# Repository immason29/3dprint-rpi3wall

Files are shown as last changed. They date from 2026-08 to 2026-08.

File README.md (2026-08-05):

# Raspberry Pi 3 wall-mount vented case

A one-piece, support-free case for a **Raspberry Pi 3 Model B** that screws flat to a
plywood wall and holds the board **20 mm off the wall** so air can move underneath it.

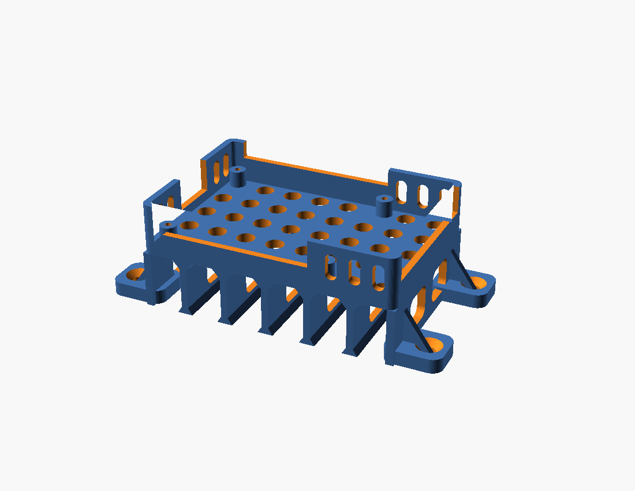
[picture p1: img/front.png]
front


## How it breathes

The case is two stacked structures. The lower one is a set of seven fins that run across
the *short* axis of the board; they carry the whole case on four countersunk ears that sit
flat against the plywood. Mounted with the long edge horizontal, those fins become vertical
chimneys — cool air enters along the bottom edge, rises through the 36 vent holes in the
back plate, passes over the board, and leaves through the open top and the wide-open port
edges. Nothing is enclosed on more than three sides.

| | |
|---|---|
| Air gap, wall to back plate | 20 mm |
| Standoff under the PCB | 6 mm |
| Open vent area in the back plate | ~1200 mm² |
| Board sides fully open | Ethernet/USB edge, power/HDMI/AV edge, top |

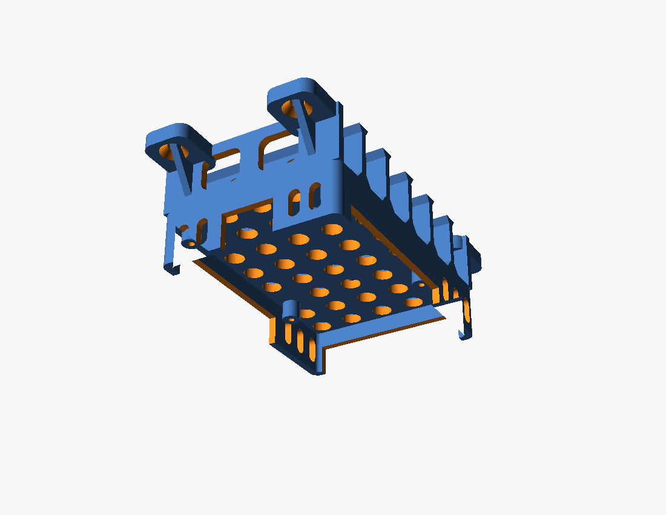
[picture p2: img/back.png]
back


## Just print it

`rpi3_wall_mount_Ender3V3SE_PLA_0.2mm.gcode` is sliced and ready. Drop it straight into
OctoPrint's Files panel and hit print — no slicer needed.

| | |
|---|---|
| Printer | Ender-3 V3 SE, 0.4 mm nozzle (stock OrcaSlicer vendor profile) |
| Material | PLA, 220 °C nozzle / 55 °C bed |
| Time | 2 h 58 m |
| Filament | 47.5 g, 15.9 m |
| Layers | 190 @ 0.2 mm |

The first thing it does is draw two prime lines down the left edge of the bed at X≈-2.
That is Creality's stock start G-code, not a mistake.

Re-slice yourself only if you want a different material or nozzle.

## Slicing it yourself

Slice `rpi3_wall_mount.stl` exactly as exported — it already sits flat on the bed in the
correct orientation.

| Setting | Value |
|---|---|
| Supports | **None** — nothing overhangs past 45° |
| Layer height | 0.2 mm |
| Perimeters | 3 (walls are 2.4 mm, so they come out fully solid) |
| Top/bottom layers | 4 |
| Infill | 15–20% (barely used; the part is nearly all wall) |
| Brim | 5 mm recommended — the fins land on the bed as thin lines |
| Material | PLA is fine. PETG if the wall gets direct sun or sits near a heat source. |
| Filament | ~55 g |
| Time | ~4 h |

Bed size needed is 121 × 62 mm, well inside the 220 × 220 bed.

The back plate bridges the gaps between fins. Each fin flares out to 8 mm at the top so the
longest unsupported bridge is about 9 mm, which the SE handles cleanly with the default
bridging settings. The feet flare to 5.5 mm for bed adhesion.

## Hardware

- **4 × M2.5 × 6 mm self-tapping screws** — hold the Pi to the four bosses. The bosses have
  2.2 mm pilot holes, so a self-tapping screw cuts its own thread. M2.5 machine screws work
  too if you tap them first.
- **4 × #8 × 25 mm flat-head wood screws** (or M4) — into the plywood. The ear holes are
  4.5 mm with a 90° countersink, so the heads sit flush.

## Mounting

Drill a rectangle of four pilot holes in the plywood:

```
    <------------ 107.8 mm ------------>

    o                                  o     ^
                                             |  43.8 mm
    o                                  o     v
```

Orientation matters for airflow — mount it so the **fins run vertically**, i.e. the long
edge of the Pi is horizontal. Put the power/HDMI/audio edge at the **bottom** so cables
hang down and out of the airflow. Ethernet and USB then face left or right, your choice of
which way you flip it.

Screw the case to the wall first, then drop the Pi in and fasten the four M2.5 screws.

## Access

Everything stays reachable with the Pi installed:

- Ethernet and both USB stacks — that entire edge is open
- micro-USB power, HDMI, AV jack — that entire edge is open
- microSD — slot in the left wall, card comes out sideways
- GPIO — the case is open on top; there is also a 6 mm notch in the top wall for a ribbon
  cable to exit
- Camera/DSI ribbon connectors — open from above

## Editing the model

`rpi3_wall_mount.scad` is parametric. The values worth touching are at the top:

```openscad
gap     = 20;   // air gap between the plywood and the back plate
tray_h  = 15;   // how far the tray walls come up past the board
boss_h  = 6;    // standoff height under the PCB
n_span  = 6;    // number of air channels across the back
```

Re-render with:

```sh
openscad -o rpi3_wall_mount.stl rpi3_wall_mount.scad
```

## Fit notes

Dimensions follow the Raspberry Pi 3 Model B mechanical spec: 85 × 56 mm board, mounting
holes 58 × 49 mm on 3.5 mm corner insets, 0.5 mm clearance per side. It also fits the
Pi 2 B and Pi 3 B+, which share the same board outline, hole pattern, and port layout.
It does **not** fit the Pi 4 (the port positions moved) or the Pi Zero.

Every connector position was checked against the model for clearance before release.
```
PCB              OK        micro-USB pwr    OK
Ethernet         OK        HDMI             OK
USB stack A      OK        AV jack          OK
USB stack B      OK        microSD card     OK
GPIO header      OK
```

## Files

| File | |
|---|---|
| `rpi3_wall_mount_Ender3V3SE_PLA_0.2mm.gcode` | ready to print, send straight to OctoPrint |
| `rpi3_wall_mount.stl` | ready to slice |
| `rpi3_wall_mount.scad` | parametric source |
| `img/` | renders |

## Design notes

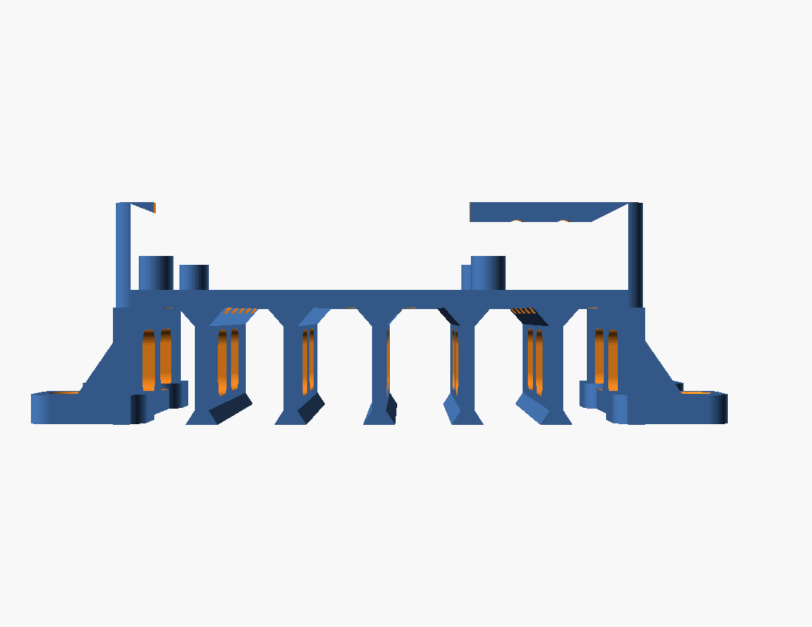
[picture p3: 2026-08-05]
img/side.png

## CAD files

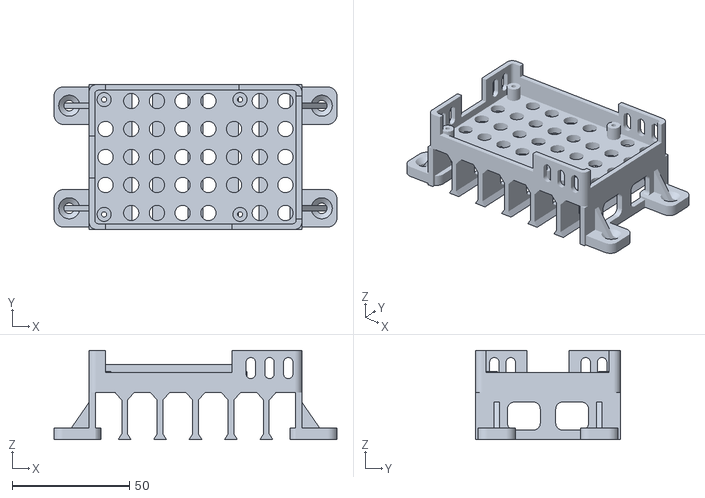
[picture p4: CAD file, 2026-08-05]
rpi3_wall_mount.stl
120.8 x 61.8 x 38.0

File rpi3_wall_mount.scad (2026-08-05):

// ============================================================================
//  Raspberry Pi 3 Model B - wall-mount vented case
//
//  Screws flat to a plywood wall through four ears. The body of the case
//  stands off the wall on a set of fins, leaving a 20 mm air gap underneath.
//  The fins run across the short axis of the board, so when the case is
//  mounted with the long edge horizontal they form vertical chimneys:
//  cool air enters at the bottom, rises through the vented back plate,
//  over the board, and out of the open top.
//
//  Prints as one piece on a Creality Ender-3 V3 SE with NO supports.
//
//  Units: mm.  z = 0 is the face of the plywood.
// ============================================================================

$fa = 2;
$fs = 0.4;

/* ------------------------------- the board ------------------------------ */
pcb_x      = 85;    // Pi 3 B PCB length
pcb_y      = 56;    // Pi 3 B PCB width
hole_dx    = 58;    // mounting-hole pitch, long axis
hole_dy    = 49;    // mounting-hole pitch, short axis
hole_inset = 3.5;   // hole centre from the PCB corner

/* ------------------------------ fit / walls ----------------------------- */
fit   = 0.5;    // clearance around the PCB, per side
wall  = 2.4;    // tray wall thickness
end_t = 2.8;    // the two end walls of the standoff stage
fin_t = 2.4;    // internal air-channel fins

/* ------------------------- heights above the wall ----------------------- */
gap       = 20;   // air gap: plywood -> underside of the back plate
plate_t   = 3;    // vented back plate
boss_h    = 6;    // PCB standoff height above the plate
boss_d    = 6;
boss_hole = 2.2;  // self-tapping pilot hole for an M2.5 screw
tray_h    = 15;   // tray wall height above the back plate

/* ------------------------------ mount ears ------------------------------ */
ear_l    = 15;    // how far an ear sticks out sideways
ear_w    = 16;
ear_t    = 5;
ear_hole = 4.5;   // shank clearance for a #8 or M4 wood screw
ear_cs   = 9;     // countersink diameter

/* -------------------------------- vents --------------------------------- */
vent_d     = 6.5;
vent_pitch = 10.5;
vent_edge  = 7;    // margin from plate edge to the nearest vent centre
n_span     = 6;    // air channels across the back -> n_span-1 internal fins

/* ------------------------------- derived -------------------------------- */
tray_w = pcb_x + 2*fit + 2*wall;   // 90.8
tray_d = pcb_y + 2*fit + 2*wall;   // 61.8
px0    = wall + fit;               // PCB origin inside the tray
py0    = wall + fit;

z_plate = gap;                     // underside of the back plate
z_top   = gap + plate_t;           // top face of the back plate
z_pcb   = z_top + boss_h;          // underside of the PCB
z_rim   = z_top + tray_h;          // top of the tray walls

boss_pts = [ for (i = [0,1], j = [0,1])
             [px0 + hole_inset + i*hole_dx, py0 + hole_inset + j*hole_dy] ];

/* ============================== primitives ============================== */

// rounded rectangle, 2D, anchored at the origin
module rrect(w, d, r) {
    translate([r, r]) offset(r = r) square([w - 2*r, d - 2*r]);
}

// rounded rectangular window cut straight through the X axis
module xwindow(cx, cy, cz, wy, wz, r) {
    hull()
        for (dy = [-1, 1], dz = [-1, 1])
            translate([cx - 10, cy + dy*(wy/2 - r), cz + dz*(wz/2 - r)])
                rotate([0, 90, 0]) cylinder(h = 20, r = r);
}

// rounded vertical slot cut through the X axis
module xslot(x0, cy, xlen, z0, z1, w) {
    hull()
        for (z = [z0 + w/2, z1 - w/2])
            translate([x0, cy, z]) rotate([0, 90, 0]) cylinder(h = xlen, r = w/2);
}

// rounded vertical slot cut through the Y axis
module yslot(cx, y0, ylen, z0, z1, w) {
    hull()
        for (z = [z0 + w/2, z1 - w/2])
            translate([cx, y0, z]) rotate([-90, 0, 0]) cylinder(h = ylen, r = w/2);
}

/* =========================== standoff structure ========================== */

// Internal fin. Flared at the foot for bed adhesion, flared at the top so the
// back plate only has to bridge ~9 mm instead of the full channel width.
module fin(cx, t) {
    flare = 5.5;
    cap   = 8;
    difference() {
        union() {
            translate([cx - t/2, 0, 0]) cube([t, tray_d, gap]);
            hull() {                                      // foot
                translate([cx - flare/2, 0, 0])       cube([flare, tray_d, 0.01]);
                translate([cx - t/2, 0, 2.4])         cube([t, tray_d, 0.01]);
            }
            hull() {                                      // cap
                translate([cx - t/2, 0, gap - 3.2])    cube([t, tray_d, 0.01]);
                translate([cx - cap/2, 0, gap - 0.01]) cube([cap, tray_d, 0.01]);
            }
        }
        for (k = [1:2])
            xwindow(cx, tray_d * k / 3, gap/2, 14, 12, 3);
    }
}

// End wall. Also the anchor for the mount ears, so it keeps more material.
module end_wall(x0) {
    difference() {
        translate([x0, 0, 0]) cube([end_t, tray_d, gap]);
        for (k = [1:2])
            xwindow(x0 + end_t/2, tray_d * k / 3, gap/2, 14, 12, 3);
    }
}

/* ============================== mount ears =============================== */

// Two ears on the left-hand end; mirrored for the right.
module ear_pair() {
    for (cy = [ear_w/2 + 1, tray_d - ear_w/2 - 1]) {
        difference() {
            linear_extrude(ear_t)
                translate([-ear_l, cy - ear_w/2]) rrect(ear_l + 5, ear_w, 4);
            translate([-ear_l/2 - 1, cy, -1])
                cylinder(d = ear_hole, h = ear_t + 2);
            translate([-ear_l/2 - 1, cy, ear_t - (ear_cs - ear_hole)/2])
                cylinder(d1 = ear_hole, d2 = ear_cs,
                         h = (ear_cs - ear_hole)/2 + 0.01);
        }
        // 45-degree gusset tying the ear back into the end wall
        translate([0, cy + 1.2, 0]) rotate([90, 0, 0])
            linear_extrude(2.4)
                polygon([[-ear_l + 4, 0], [end_t, 0], [end_t, gap]]);
    }
}

/* ============================== back plate =============================== */

module back_plate() {
    translate([0, 0, z_plate]) linear_extrude(plate_t) rrect(tray_w, tray_d, 3);
}

module vent_grid() {
    nx = floor((tray_w - 2*vent_edge) / vent_pitch) + 1;
    ny = floor((tray_d - 2*vent_edge) / vent_pitch) + 1;
    sx = (tray_w - 2*vent_edge) / (nx - 1);
    sy = (tray_d - 2*vent_edge) / (ny - 1);
    for (i = [0 : nx - 1], j = [0 : ny - 1]) {
        x = vent_edge + i*sx;
        y = vent_edge + j*sy;
        if (min([for (p = boss_pts) norm([x, y] - p)]) > 8)
            translate([x, y, z_plate - 1])
                cylinder(d = vent_d, h = plate_t + 2);
    }
}

module bosses() {
    for (p = boss_pts)
        translate([p[0], p[1], z_top - 0.01])
            cylinder(d = boss_d, h = boss_h + 0.01);
}

module boss_holes() {
    for (p = boss_pts)
        translate([p[0], p[1], z_plate - 1])
            cylinder(d = boss_hole, h = plate_t + boss_h + 2);
}

/* ================================= tray ================================== */

module port_cuts() {
    zc = z_pcb - 0.5;          // start just under the PCB
    h  = z_rim - zc + 3;       // and run out through the open top

    // Ethernet + both USB stacks: the whole right-hand edge
    translate([tray_w - wall - 1, py0 + 1.5, zc]) cube([wall + 2, 52.5, h]);

    // micro-USB power, HDMI and the AV jack: bottom edge
    translate([px0 + 4, -1, zc]) cube([54, wall + 2, h]);

    // microSD card, which sits under the board: left edge
    translate([-1, py0 + 19, z_top + 3.5]) cube([wall + 2, 18, tray_h]);

    // notch for a GPIO ribbon cable: top edge
    translate([px0 + 4, tray_d - wall - 1, z_rim - 6]) cube([57, wall + 2, 8]);

    // extra vent slots in the wall that is left over on each edge
    for (cx = [69, 77, 85]) {
        yslot(cx, -1, wall + 2, z_top + 3, z_rim - 3, 4);
        yslot(cx, tray_d - wall - 1, wall + 2, z_top + 3, z_rim - 3, 4);
    }
    for (cy = [8, 15, 47, 54])
        xslot(-1, cy, wall + 2, z_top + 3, z_rim - 3, 4);
}

module tray_walls() {
    difference() {
        translate([0, 0, z_top]) linear_extrude(tray_h)
            difference() {
                rrect(tray_w, tray_d, 3);
                translate([wall, wall]) rrect(tray_w - 2*wall, tray_d - 2*wall, 1.5);
            }
        port_cuts();
    }
}

/* =============================== assembly ================================ */

module rpi3_wall_mount() {
    difference() {
        union() {
            end_wall(0);
            end_wall(tray_w - end_t);
            for (i = [1 : n_span - 1]) fin(tray_w * i / n_span, fin_t);
            back_plate();
            tray_walls();
            bosses();
            ear_pair();
            translate([tray_w, 0, 0]) mirror([1, 0, 0]) ear_pair();
        }
        vent_grid();
        boss_holes();
    }
}

rpi3_wall_mount();

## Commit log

2026-08-05 Raspberry Pi 3 wall-mount vented case
    One-piece, support-free case for a Pi 3 Model B that screws to a plywood
    wall and stands the board 20 mm off it. Seven fins across the short axis
    form vertical chimneys; a 36-hole vented back plate carries the board on
    6 mm standoffs. Ethernet/USB and power/HDMI/AV edges are fully open, as
    is the top.
    Prints flat as exported on an Ender-3 V3 SE, no supports: fin tops flare
    to 8 mm so the back plate bridges only ~9 mm, feet flare to 5.5 mm for
    adhesion. ~55 g, ~4 h, 121 x 62 x 38 mm.
    Verified watertight, single connected body, and clear of all nine
    connector envelopes.
    Claude-Session: https://claude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
    [rpi3_wall_mount.scad, rpi3_wall_mount.stl]
2026-08-05 Add ready-to-print gcode for the Ender-3 V3 SE
    Sliced with OrcaSlicer 2.4.2 against the stock Creality Ender-3 V3 SE
    0.4 nozzle vendor profile, so the start G-code and its leveling/prime
    routine are Creality's own rather than hand-authored.
    PLA 220/55, 0.2 mm layers, 3 walls, 4 top/bottom, 20% infill, no
    supports, 5 mm outer brim. 190 layers, 2h58m, 47.5 g.
    Verified against the sliced output: no support extrusions emitted, brim
    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
